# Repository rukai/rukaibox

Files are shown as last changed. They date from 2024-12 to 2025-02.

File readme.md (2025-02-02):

# Rukaibox

A custom hitbox controller for platform fighters.
The PCB used is the [gram slim PCB](https://gramctrl.com/products/gram-slim-pcb)
I have a fork of the PCB in this repo purely because I wanted to tweak some things for my own usage while remaining compatible with the standard gram slim PCB.

This design might be interesting to you if you want a fully 3D printable enclosure with a built in lid that flips underneath the controller when in use.
But keep in mind that when the lid is open, it exposes the PCB as an aesthetic choice, which comes with a risk of damage to the PCB.

I also personally use my own [rukaibox firmware](https://github.com/rukai/rukaibox_firmware).
But the [stock gram haybox firmware](https://github.com/GRAMCTRL/HayBox-GRAM) also works just fine and supports a wider range of protocols, games and MCUs.

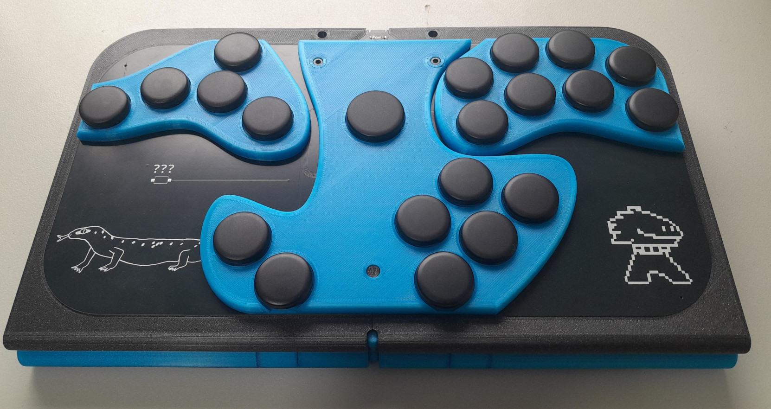
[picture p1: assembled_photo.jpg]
assembled photo

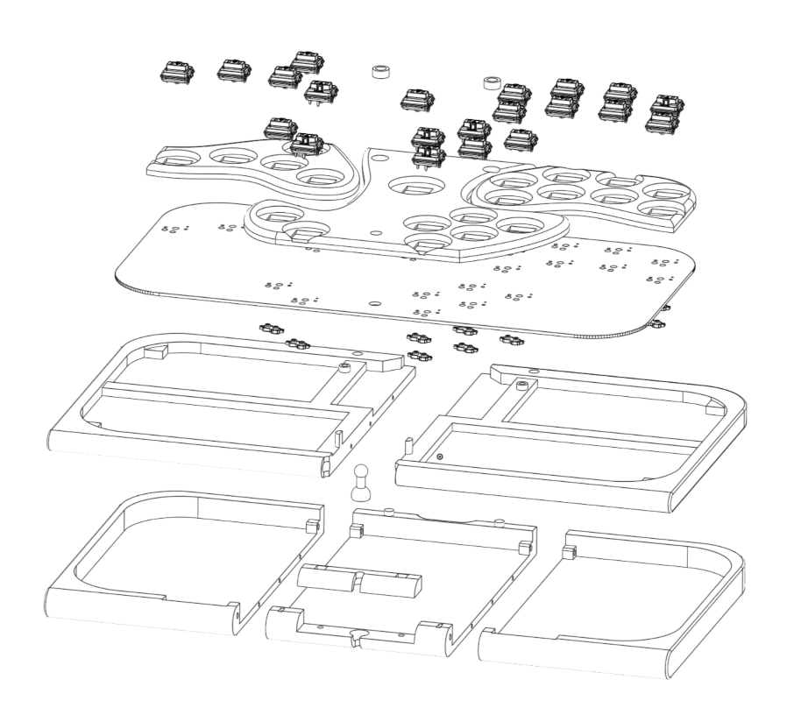
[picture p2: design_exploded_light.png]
Exploded design


## BOM

* A gram slim PCB
  * I ordered mine from jlcpcb from the designs in this repo
  * But you should probably just buy yours from <https://gramctrl.com/products/gram-slim-pcb>
* All the printed parts from [the onshape designs](https://cad.onshape.com/documents/f6e7916fda654a648d842c67/w/2435c624e0afcf5d47216714/e/d2b4fc9888a125d6f744d329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).
  1. Convert each part to an STL by going through the `base`, `lid`, `switch plate`, `switch plate left`, `switch plate right`, `join` and `woshua` tabs at the bottom of the page.
  For each tab, click on the tab and then right click on each part on the pane on the left and select export.
  Set the format to STL and keep the rest as default.
  2. Then slice and print each STL yourself.
* M3 Screws (all with head length 3mm, head width 5.3mm):
  * 6 X [bolt length: 13.5mm](https://www.aliexpress.com/item/32810872544.html)
* 6 X [M3 square nuts 5.45mm x 5.45mm x 1.7mm](https://www.aliexpress.com/item/1005001612157787.html)
* 21 x [kailh choc hotswap sockets](https://www.aliexpress.com/item/1005003575767699.html)
* 21 x [kailh choc V1 switches](https://www.aliexpress.com/item/1005005066585322.html) (I used whites for the start button and reds for every other button)
* 21 x [kailh choc V1 buttons](https://www.aliexpress.com/item/1005006902597750.html)

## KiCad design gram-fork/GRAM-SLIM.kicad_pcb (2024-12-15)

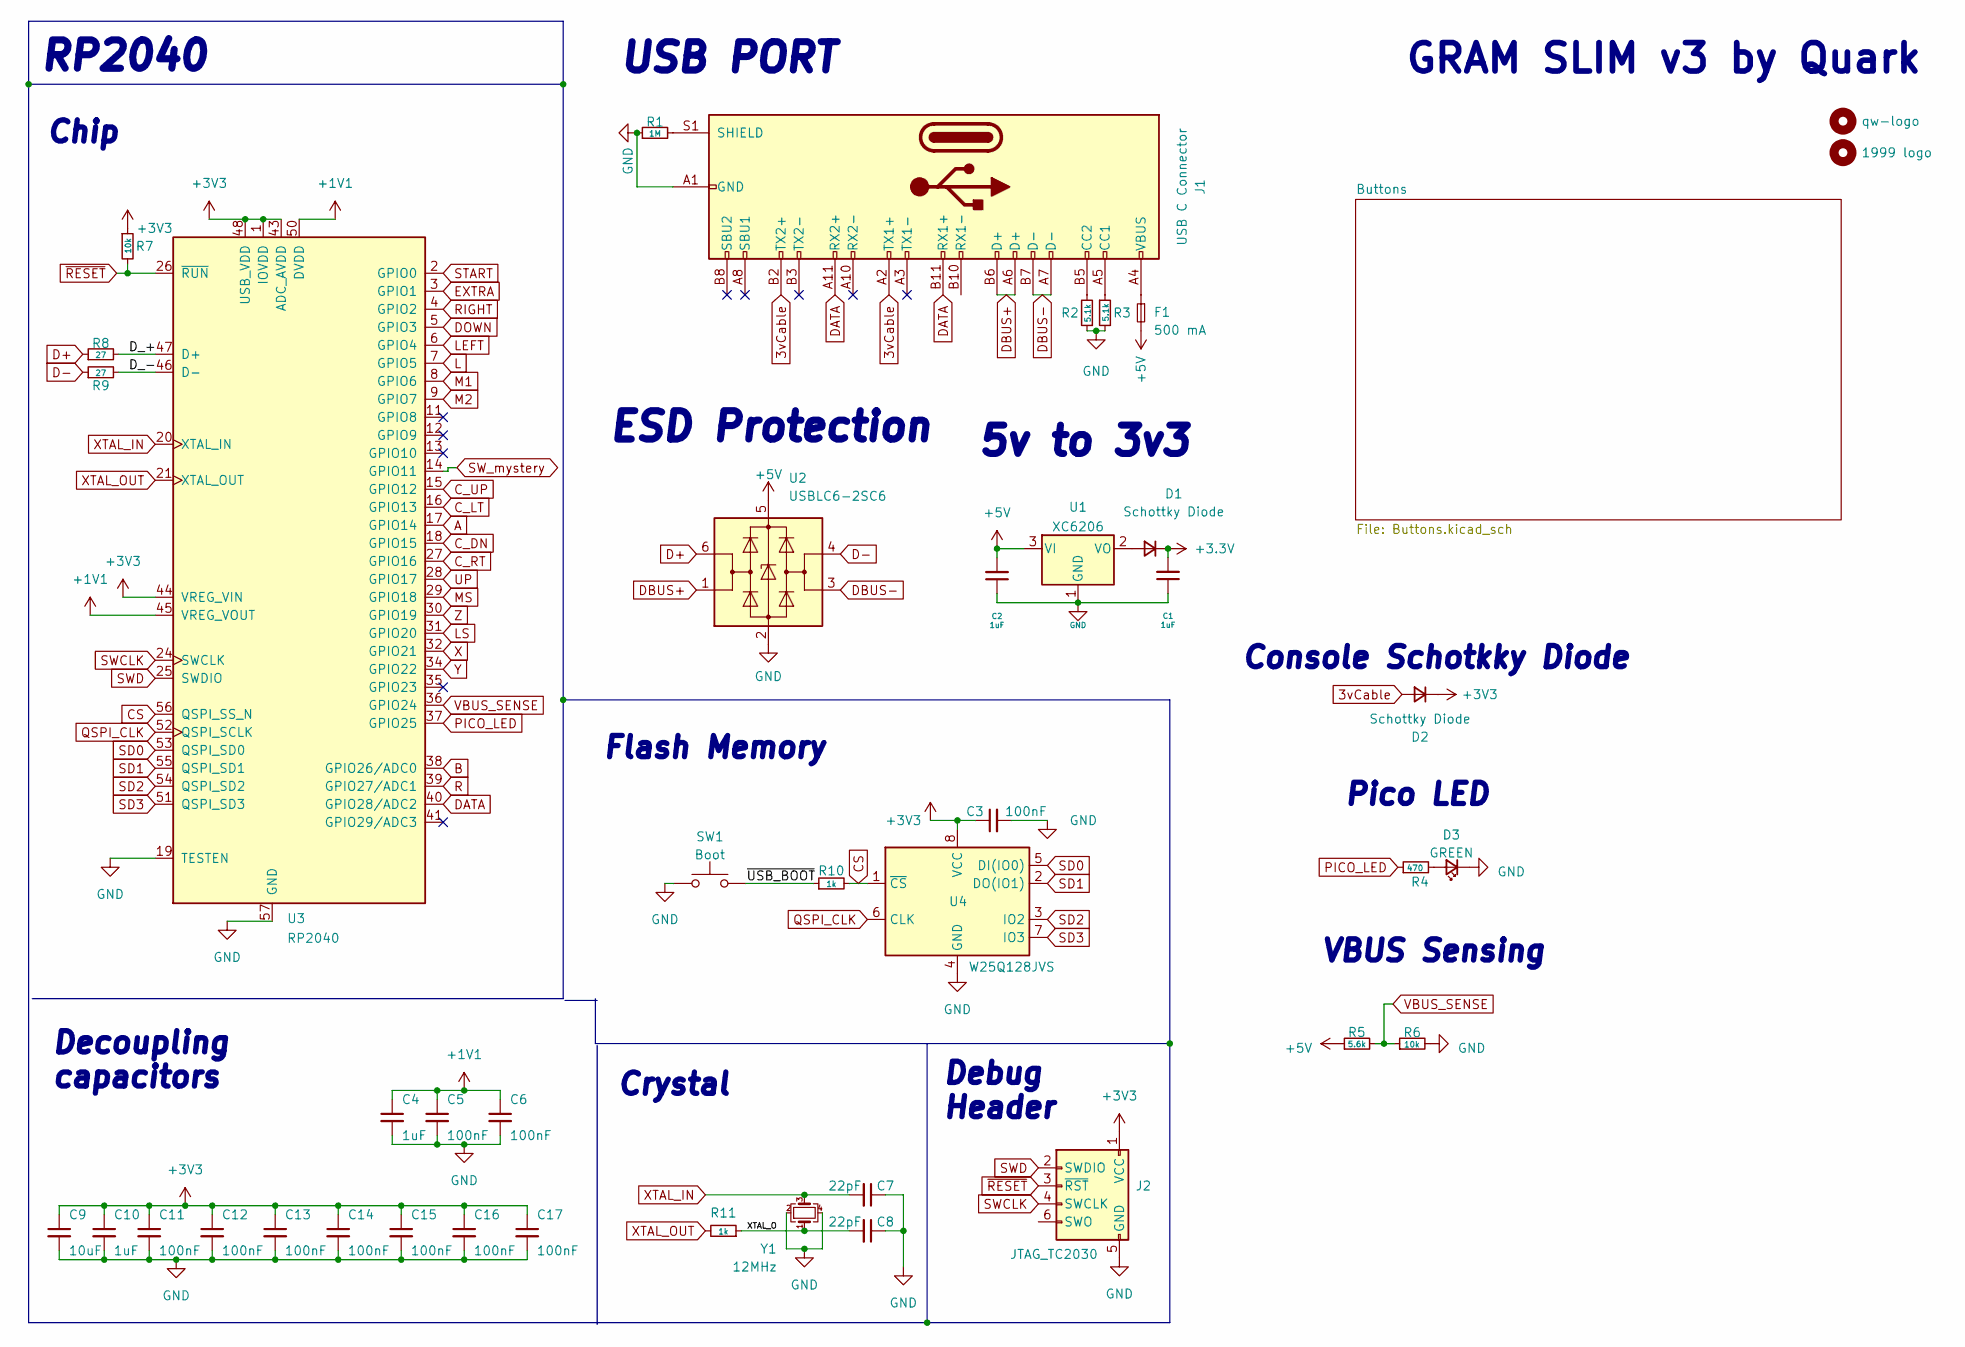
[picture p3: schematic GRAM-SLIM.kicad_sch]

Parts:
C1, C2, C4, C10: 1uF; C_0402_1005Metric; LCSC C52923
C3, C5, C6, C11, C12, C13, C14, C15, C16, C17: 100nF; C_0402_1005Metric; LCSC C1525
C7, C8: 22pF; C_0402_1005Metric; LCSC C1555
C9: 10uF; C_0402_1005Metric; LCSC C15525
D1, D2: Schottky Diode; D_SOD-123; LCSC C130880
D3: GREEN; LED_0805_2012Metric
F1: 500 mA; Fuse_1206_3216Metric
H1: qw-logo; qw new logo silk + copper md
H2: 1999 logo; 1999 logo md
J1: USB C Connector; TYPE-C_24P_QCHT; LCSC C456013
J2: JTAG_TC2030; CON_TC2030_outlined
R1: 1M; R_0603_1608Metric; LCSC C25190
R2, R3: 5.1k; R_0402_1005Metric; LCSC C25744
R4: 470; R_0402_1005Metric
R5: 5.6k; R_0603_1608Metric
R6: 10k; R_0603_1608Metric
R7: 10k; R_0402_1005Metric; LCSC C25744
R8, R9: 27; R_0603_1608Metric; LCSC C25190
R10, R11: 1k; R_0402_1005Metric; LCSC C11702
SW1: Boot; SW_SPST_SKQG_WithStem; LCSC C5156480
U1: XC6206; SOT-23; LCSC C5446
U2: USBLC6-2SC6; SOT-23-6
U3: RP2040; RP2040-QFN-56; LCSC C2040
U4: W25Q128JVS; SOIC-8_5.23x5.23mm_P1.27mm; LCSC C97521
Y1: 12MHz; Crystal_SMD_3225-4Pin_3.2x2.5mm; LCSC C9002

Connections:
3vCable: D2.2 (A), J1.A2 (TX1+), J1.B2 (TX2+)
+1V1: C4.1, C5.1, C6.1, U3.23 (DVDD), U3.45 (VREG_VOUT), U3.50 (DVDD)
+5V: C2.2, F1.2, R5.1, U1.3 (VI), U2.5 (VBUS)
/D_+: R8.2, U3.47 (D+)
/D_-: R9.2, U3.46 (D-)
/XTAL_O: C8.2, R11.1, Y1.1
/~USB_BOOT: R10.1, SW1.2
A: U3.17 (GPIO14); also elsewhere on the board
B: U3.38 (GPIO26/ADC0); also elsewhere on the board
CS: R10.2, U3.56 (QSPI_SS_N), U4.1 (~CS)
C_DN: U3.18 (GPIO15); also elsewhere on the board
C_LT: U3.16 (GPIO13); also elsewhere on the board
C_RT: U3.27 (GPIO16); also elsewhere on the board
C_UP: U3.15 (GPIO12); also elsewhere on the board
D+: R8.1, U2.6 (I/O1)
D-: R9.1, U2.4 (I/O2)
DATA: J1.A11 (RX2+), J1.B11 (RX1+), U3.40 (GPIO28/ADC2)
DBUS+: J1.A6 (D+), J1.B6 (D+), U2.1 (I/O1)
DBUS-: J1.A7 (D-), J1.B7 (D-), U2.3 (I/O2)
DOWN: U3.5 (GPIO3); also elsewhere on the board
EXTRA: U3.3 (GPIO1); also elsewhere on the board
GND: C1.1, C2.1, C3.2, C4.2, C5.2, C6.2, C7.1, C8.1, C9.2, C10.2, C11.2, C12.2, C13.2, C14.2, C15.2, C16.2, C17.2, D3.1 (K), J1.A1 (GND), J1.A12 (GND), J1.B1 (GND), J1.B12 (GND), J2.5 (GND), R1.1, R2.1, R3.2, R6.2, SW1.1, U1.1 (GND), U2.2 (GND), U3.19 (TESTEN), U3.57 (GND), U4.4 (GND), Y1.2, Y1.4; also elsewhere on the board
L: U3.7 (GPIO5); also elsewhere on the board
LEFT: U3.6 (GPIO4); also elsewhere on the board
LS: U3.31 (GPIO20); also elsewhere on the board
M1: U3.8 (GPIO6); also elsewhere on the board
M2: U3.9 (GPIO7); also elsewhere on the board
MS: U3.29 (GPIO18); also elsewhere on the board
unnamed: D1.2 (A), U1.2 (VO)
unnamed: D3.2 (A), R4.2
unnamed: F1.1, J1.A4 (VBUS), J1.A9 (VBUS), J1.B4 (VBUS), J1.B9 (VBUS)
unnamed: J1.A5 (CC1), R3.1
unnamed: J1.B5 (CC2), R2.2
unnamed: J1.S1 (SHIELD), R1.2
PICO_LED: R4.1, U3.37 (GPIO25)
QSPI_CLK: U3.52 (QSPI_SCLK), U4.6 (CLK)
R: U3.39 (GPIO27/ADC1); also elsewhere on the board
RIGHT: U3.4 (GPIO2); also elsewhere on the board
SD0: U3.53 (QSPI_SD0), U4.5 (DI(IO0))
SD1: U3.55 (QSPI_SD1), U4.2 (DO(IO1))
SD2: U3.54 (QSPI_SD2), U4.3 (IO2)
SD3: U3.51 (QSPI_SD3), U4.7 (IO3)
START: U3.2 (GPIO0); also elsewhere on the board
SWCLK: J2.4 (SWCLK), U3.24 (SWCLK)
SWD: J2.2 (SWDIO), U3.25 (SWDIO)
SW_mystery: U3.14 (GPIO11); also elsewhere on the board
UP: U3.28 (GPIO17); also elsewhere on the board
VBUS_SENSE: R5.2, R6.1, U3.36 (GPIO24)
X: U3.32 (GPIO21); also elsewhere on the board
XTAL_IN: C7.2, U3.20 (XTAL_IN), Y1.3
XTAL_OUT: R11.2, U3.21 (XTAL_OUT)
Y: U3.34 (GPIO22); also elsewhere on the board
Z: U3.30 (GPIO19); also elsewhere on the board
~RESET: J2.3 (~RST), R7.2, U3.26 (~RUN)

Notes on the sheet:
GRAM SLIM v3 by Quark
Flash Memory
5v to 3v3
Pico LED
Crystal
Chip
Console Schotkky Diode
RP2040
VBUS Sensing
Debug Header
USB PORT
ESD Protection
Decoupling capacitors

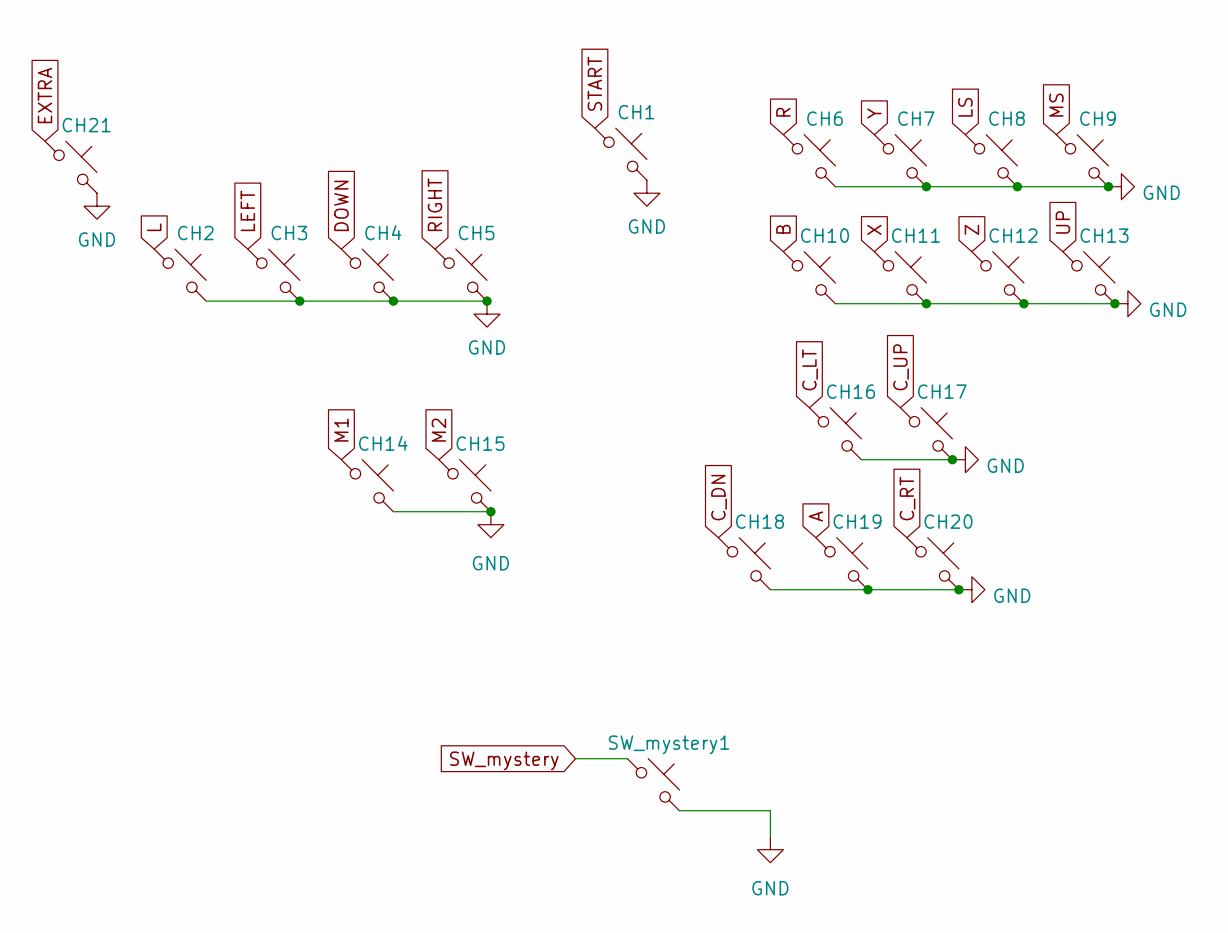
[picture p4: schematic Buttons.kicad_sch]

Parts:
CH1, CH2, CH3, CH4, CH5, CH6, CH7, CH8, CH9, CH10, CH11, CH12, CH13, CH14, CH15, CH16, CH17, CH18, CH19, CH20, CH21: choc_SW_HS; SW_choc_v1_HS_1u
SW_mystery1: SW_mystery??; SW_SPST_CK_RS282G05A3; JLCPCB Part # C5117870

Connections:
A: CH19.1; also elsewhere on the board
B: CH10.1; also elsewhere on the board
C_DN: CH18.1; also elsewhere on the board
C_LT: CH16.1; also elsewhere on the board
C_RT: CH20.1; also elsewhere on the board
C_UP: CH17.1; also elsewhere on the board
DOWN: CH4.1; also elsewhere on the board
EXTRA: CH21.1; also elsewhere on the board
GND: CH1.2, CH2.2, CH3.2, CH4.2, CH5.2, CH6.2, CH7.2, CH8.2, CH9.2, CH10.2, CH11.2, CH12.2, CH13.2, CH14.2, CH15.2, CH16.2, CH17.2, CH18.2, CH19.2, CH20.2, CH21.2, SW_mystery1.2; also elsewhere on the board
L: CH2.1; also elsewhere on the board
LEFT: CH3.1; also elsewhere on the board
LS: CH8.1; also elsewhere on the board
M1: CH14.1; also elsewhere on the board
M2: CH15.1; also elsewhere on the board
MS: CH9.1; also elsewhere on the board
R: CH6.1; also elsewhere on the board
RIGHT: CH5.1; also elsewhere on the board
START: CH1.1; also elsewhere on the board
SW_mystery: SW_mystery1.1; also elsewhere on the board
UP: CH13.1; also elsewhere on the board
X: CH11.1; also elsewhere on the board
Y: CH7.1; also elsewhere on the board
Z: CH12.1; also elsewhere on the board

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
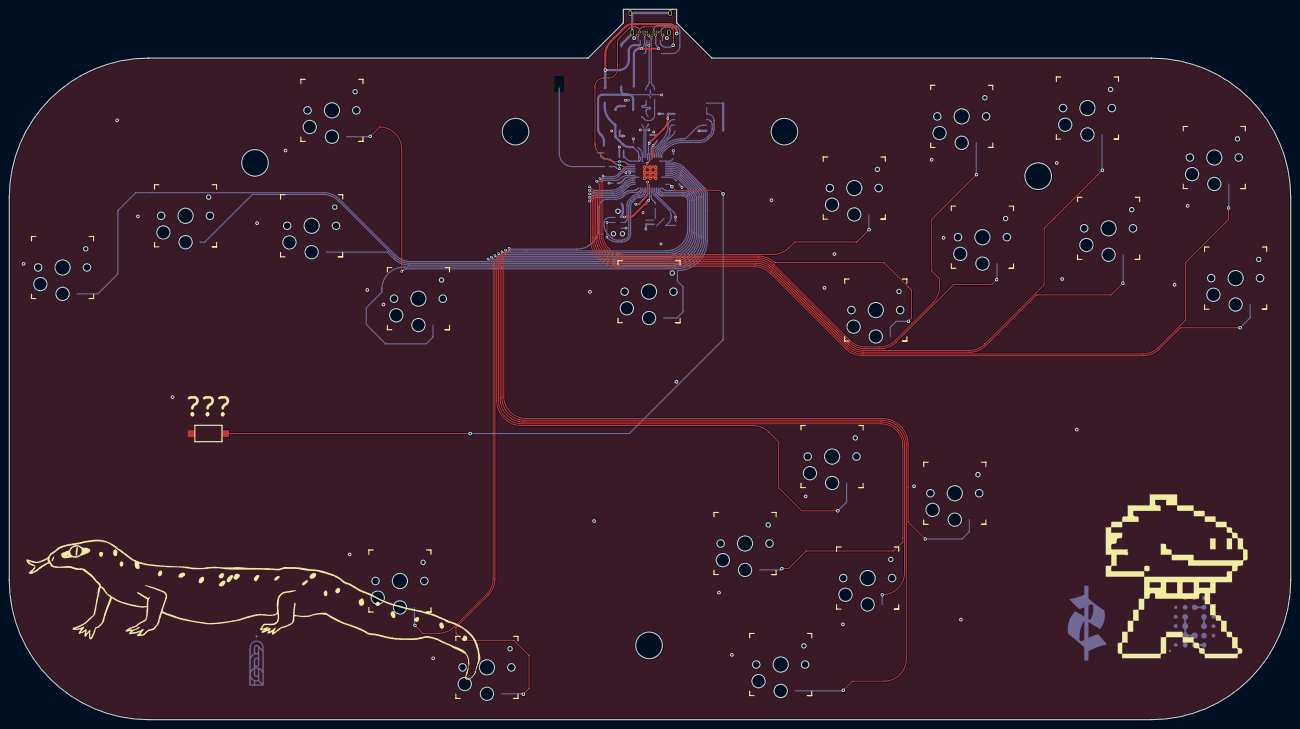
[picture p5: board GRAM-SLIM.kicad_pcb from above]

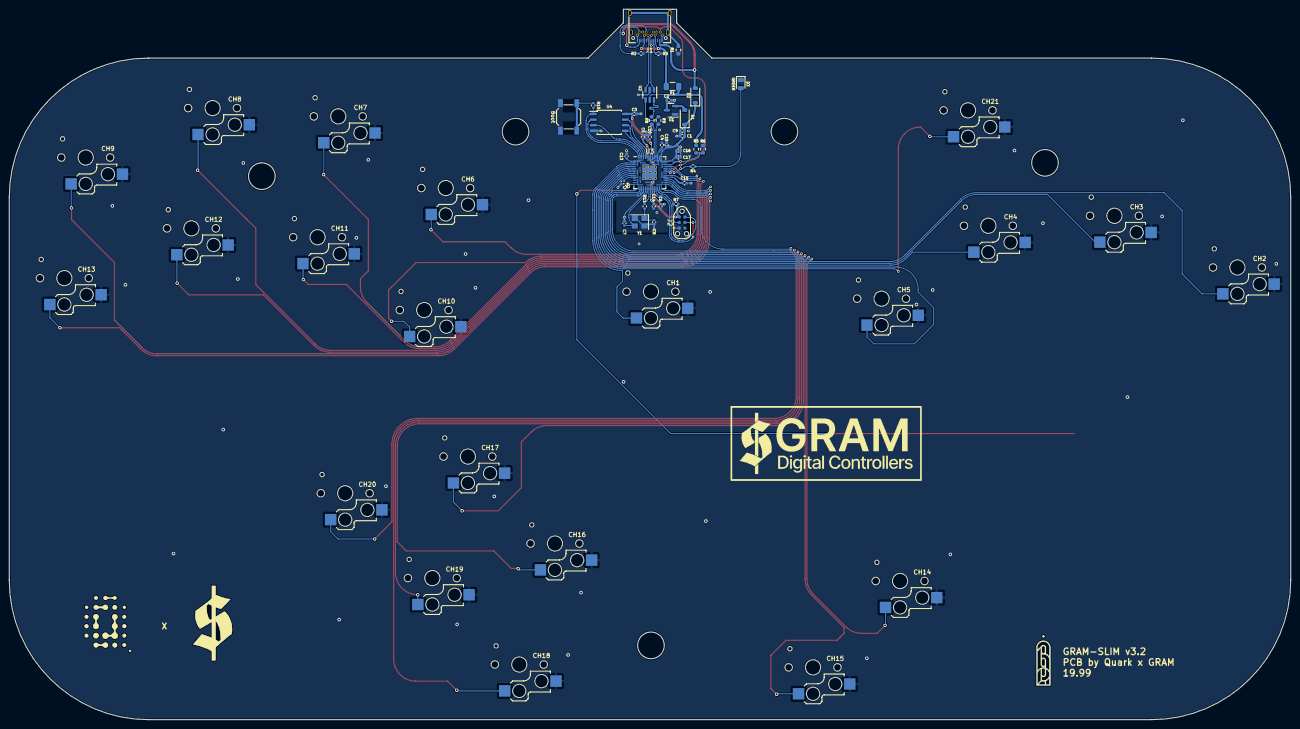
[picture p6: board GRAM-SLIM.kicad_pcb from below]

Board: 2 copper layers, 288.8 x 160.1 mm, 64 parts (42 on the bottom side), 55 nets.
